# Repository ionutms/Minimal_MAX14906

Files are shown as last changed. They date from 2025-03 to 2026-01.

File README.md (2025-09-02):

# Minimal_MAX14906

## Overview

This repository contains a minimal KiCad design project for the Analog Devices MAX14906, a quad-channel industrial digital I/O device. The project includes schematic designs and PCB layout files.

## Disclaimer

> [!NOTE]
> This project is provided "as is" and without any warranty, express or implied. For more details, please see the [LICENSE](LICENSE) file.

## About the MAX14906

The MAX14906 from Analog Devices is a quad-channel industrial digital input/output device for industrial control and automation applications. It is compliant with IEC 61131-2 standards.

Key features include:

- **Configurable Channels:** Each of the four channels can be independently configured as:
  - High-Side Switch
  - Push-Pull Driver
  - Digital Input (Type 1, 2, or 3)
- **Wide Operating Range:** 10V to 40V supply voltage range.
- **Robustness and Protection:** Features on-chip diagnostics like open-wire detection, thermal shutdown and undervoltage monitoring. It also features SafeDemag™ for safely turning off inductive loads.
- **Control Interface:** SPI interface for configuration and diagnostics.
- **Operating Temperature Range:** -40°C to +125°C.

## Project Structure

```
minimal_max14906/
├── minimal_max14906.kicad_sch       # Main schematic file
├── minimal_max14906.kicad_pcb       # PCB layout file
├── minimal_max14906.kicad_pro       # Project configuration file
├── fp-lib-table                     # Footprint library table
├── sym-lib-table                    # Symbol library table
├── project_jobs_set.kicad_jobset    # Project job settings
├── ibom.config.ini                  # Interactive BOM configuration
├── docs/                            # Documentation files
│   ├── pictures/                    # Images and photos
│   ├── schematics/                  # Schematic PDF exports
│   └── 3d_models/                   # 3D model files
└── KiCAD_Symbols_Generator/         # Submodule for symbol generation from CSV data
```

## Project Features

This design provides a minimal implementation of the MAX14906 with the following features:

- **Power Supply:**
  - VDD: +24V
  - VSS: 0V
  - VLOGIC: +3.3V
- **Channel Configuration:**
  - Basic protection circuits for each of the four I/O channels.
- **Bill of Materials (BOM):**
  - Interactive HTML BOM (`ibom.html`) for easy component identification and sourcing.
- **Libraries:**
  - Comprehensive symbol and footprint libraries integrated as a submodule.
- **3D Model:**
  - Includes a 3D model of the board for better visualization.

## Getting Started

### Prerequisites

- [KiCad EDA](https://www.kicad.org/) version 9.0 or later installed on your system
- Git (for cloning the repository and submodule management)

### Opening the Project

1. **Clone the repository** (including submodules):
   ```bash
   git clone --recursive https://github.com/ionutms/Minimal_MAX14906.git
   ```
   
   If you've already cloned the repository without submodules, initialize them with:
   ```bash
   git submodule init
   git submodule update
   ```

2. **Open the project in KiCad**:
   - Launch KiCad
   - Click "Open Existing Project"
   - Navigate to the cloned repository folder
   - Select the `minimal_max14906.kicad_pro` file

3. **Explore the design**:
   - Open the schematic editor to view the circuit design
   - Open the PCB editor to view the board layout
   - Review the symbol and footprint libraries used in the design

### Project Files

- **Main schematic**: `minimal_max14906.kicad_sch` - Contains the primary circuit design with the MAX14906 and support components
- **PCB layout**: `minimal_max14906.kicad_pcb` - Physical board design file with proper component placement
- **Project configuration**: `minimal_max14906.kicad_pro` - KiCad project settings

## Dependencies

This project has the following dependencies:

### 1. KiCAD Symbols Generator

This repository uses [KiCAD_Symbols_Generator](https://github.com/ionutms/KiCAD_Symbols_Generator) as a submodule for custom symbol generation.

To initialize the submodule after cloning this repository:

```bash
git submodule update --init --recursive
```

### 2. 3D Models

This project requires the [3D_Models_Vault](https://github.com/ionutms/3D_Models_Vault) repository for 3D models.

#### Setup for KiCAD 9:

1. Clone the 3D models repository:
   ```bash
   git clone https://github.com/ionutms/3D_Models_Vault.git
   ```

2. In KiCAD 9, add an environment variable:
   - Variable name: `KICAD9_3D_MODELS_VAULT`
   - Variable value: Full path to where you cloned the 3D_Models_Vault repository

## Usage

After setting up the dependencies, open the project in KiCad 9 to access all features including the 3D models.

## Symbol Generator Submodule

This project includes the KiCAD_Symbols_Generator as a submodule, which provides tools for generating KiCad symbols from CSV data files. For more information on using this tool, see the [KiCAD_Symbols_Generator documentation](minimal_max14906/KiCAD_Symbols_Generator/README.md).

## Documentation

The `docs` folder contains:
- Schematic PDF exports
- Images and photos of the design
- 3D model files (GLB and WRL formats)

## Visuals

The following images showcase the PCB design from different perspectives:

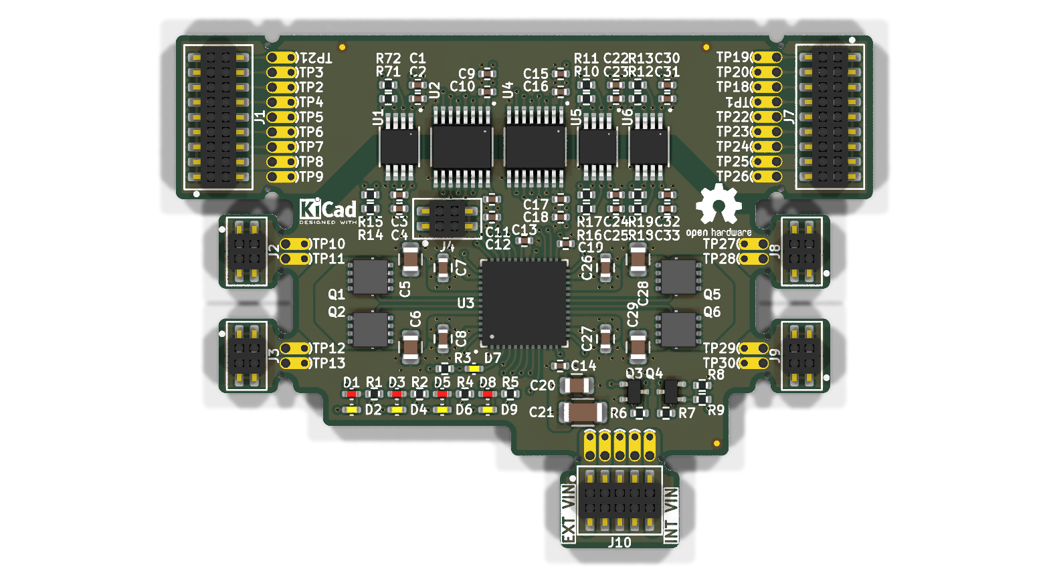
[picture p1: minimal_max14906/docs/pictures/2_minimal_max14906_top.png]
Top View

*Top View of the PCB*

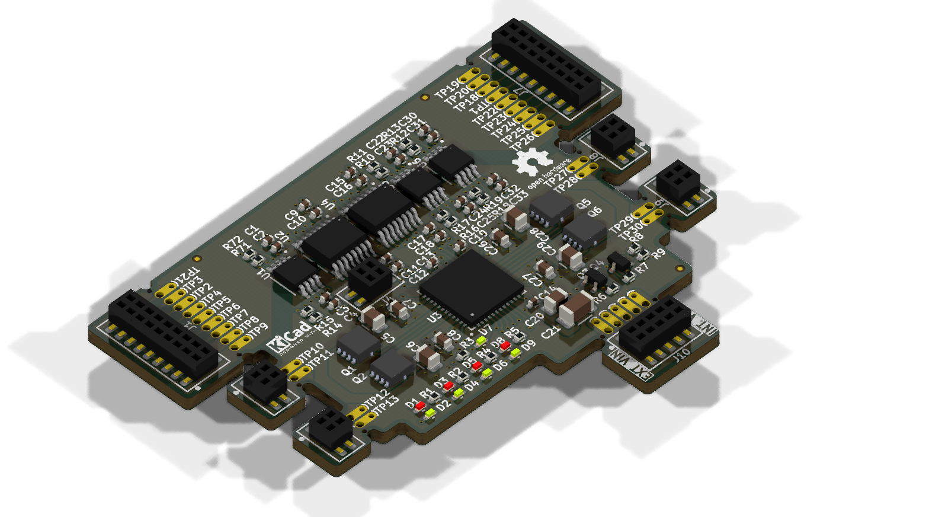
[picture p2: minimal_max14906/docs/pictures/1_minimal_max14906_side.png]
Side View

*Side View of the PCB*

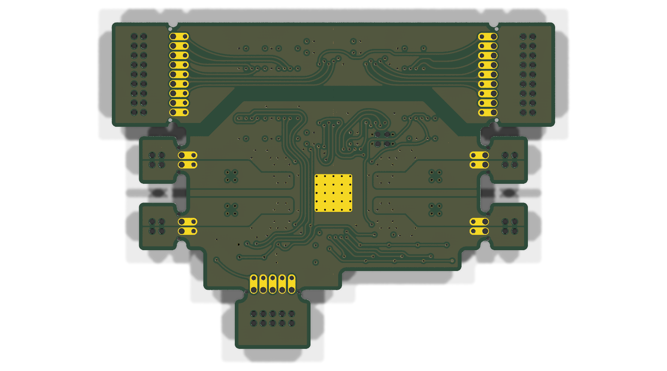
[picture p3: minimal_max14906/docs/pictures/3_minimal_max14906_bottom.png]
Bottom View

*Bottom View of the PCB*

## License

This project is licensed under the MIT License - see the [LICENSE](LICENSE) file for details.

## References

- [MAX14906 Datasheet](https://www.analog.com/en/products/max14906.html)
- [KiCad EDA](https://www.kicad.org/)

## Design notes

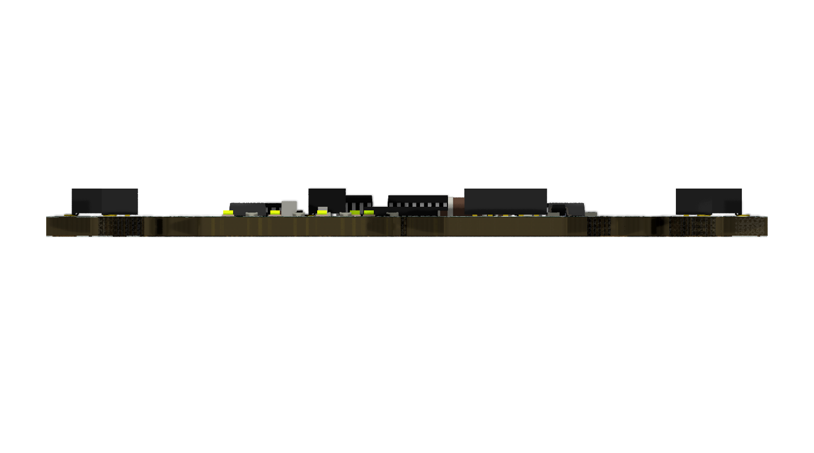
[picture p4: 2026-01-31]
minimal_max14906/docs/pictures/6_minimal_max14906_front.png

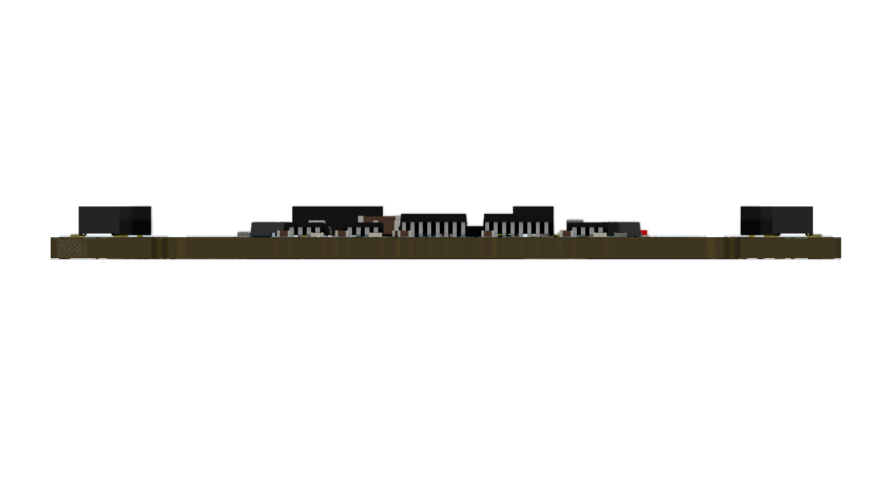
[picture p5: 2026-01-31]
minimal_max14906/docs/pictures/7_minimal_max14906_back.png

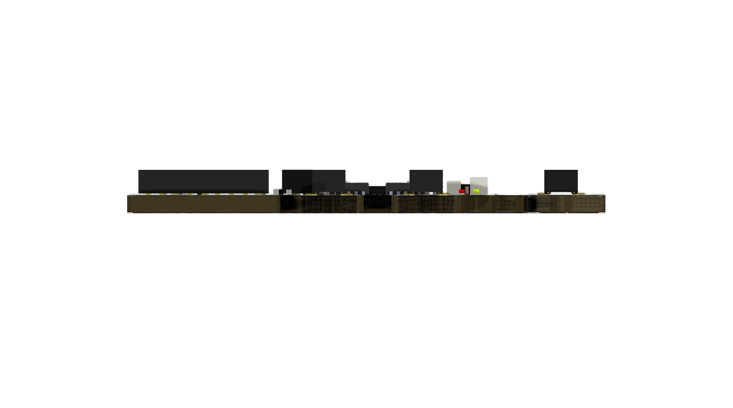
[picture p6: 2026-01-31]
minimal_max14906/docs/pictures/4_minimal_max14906_left.png

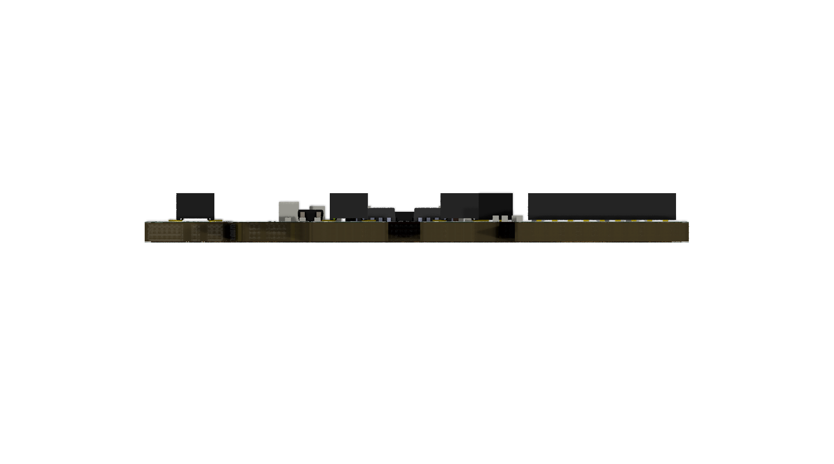
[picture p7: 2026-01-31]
minimal_max14906/docs/pictures/5_minimal_max14906_right.png

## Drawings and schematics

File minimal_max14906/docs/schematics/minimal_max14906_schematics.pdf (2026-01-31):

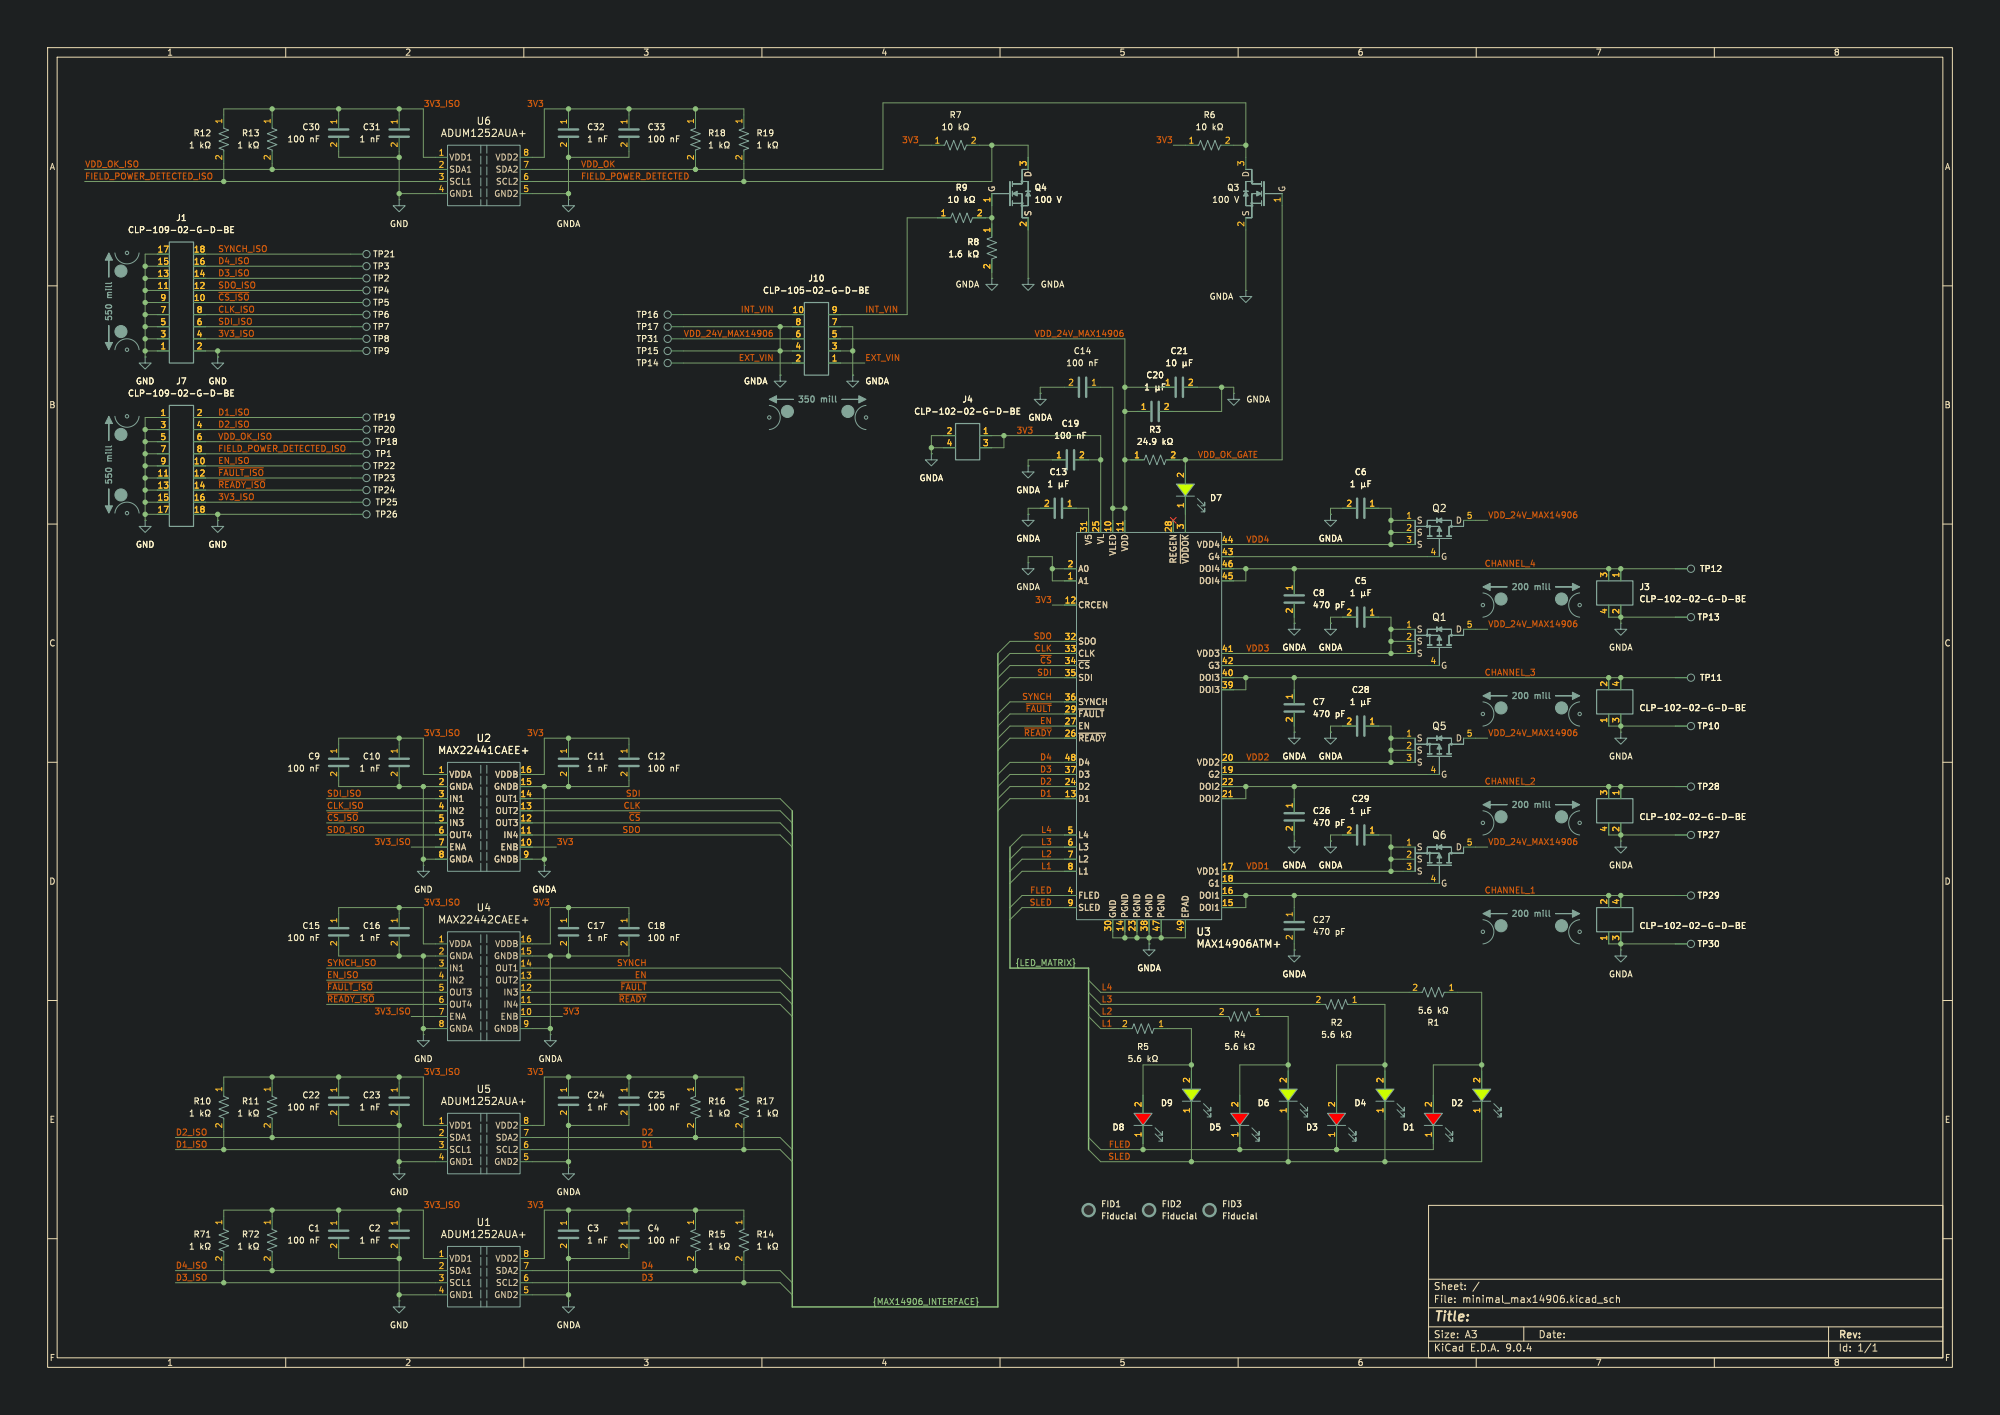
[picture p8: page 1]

~{READY} SDI ~{CS} SDO

Id: 1/1 Title: File: minimal_max14906.kicad_sch Sheet: /

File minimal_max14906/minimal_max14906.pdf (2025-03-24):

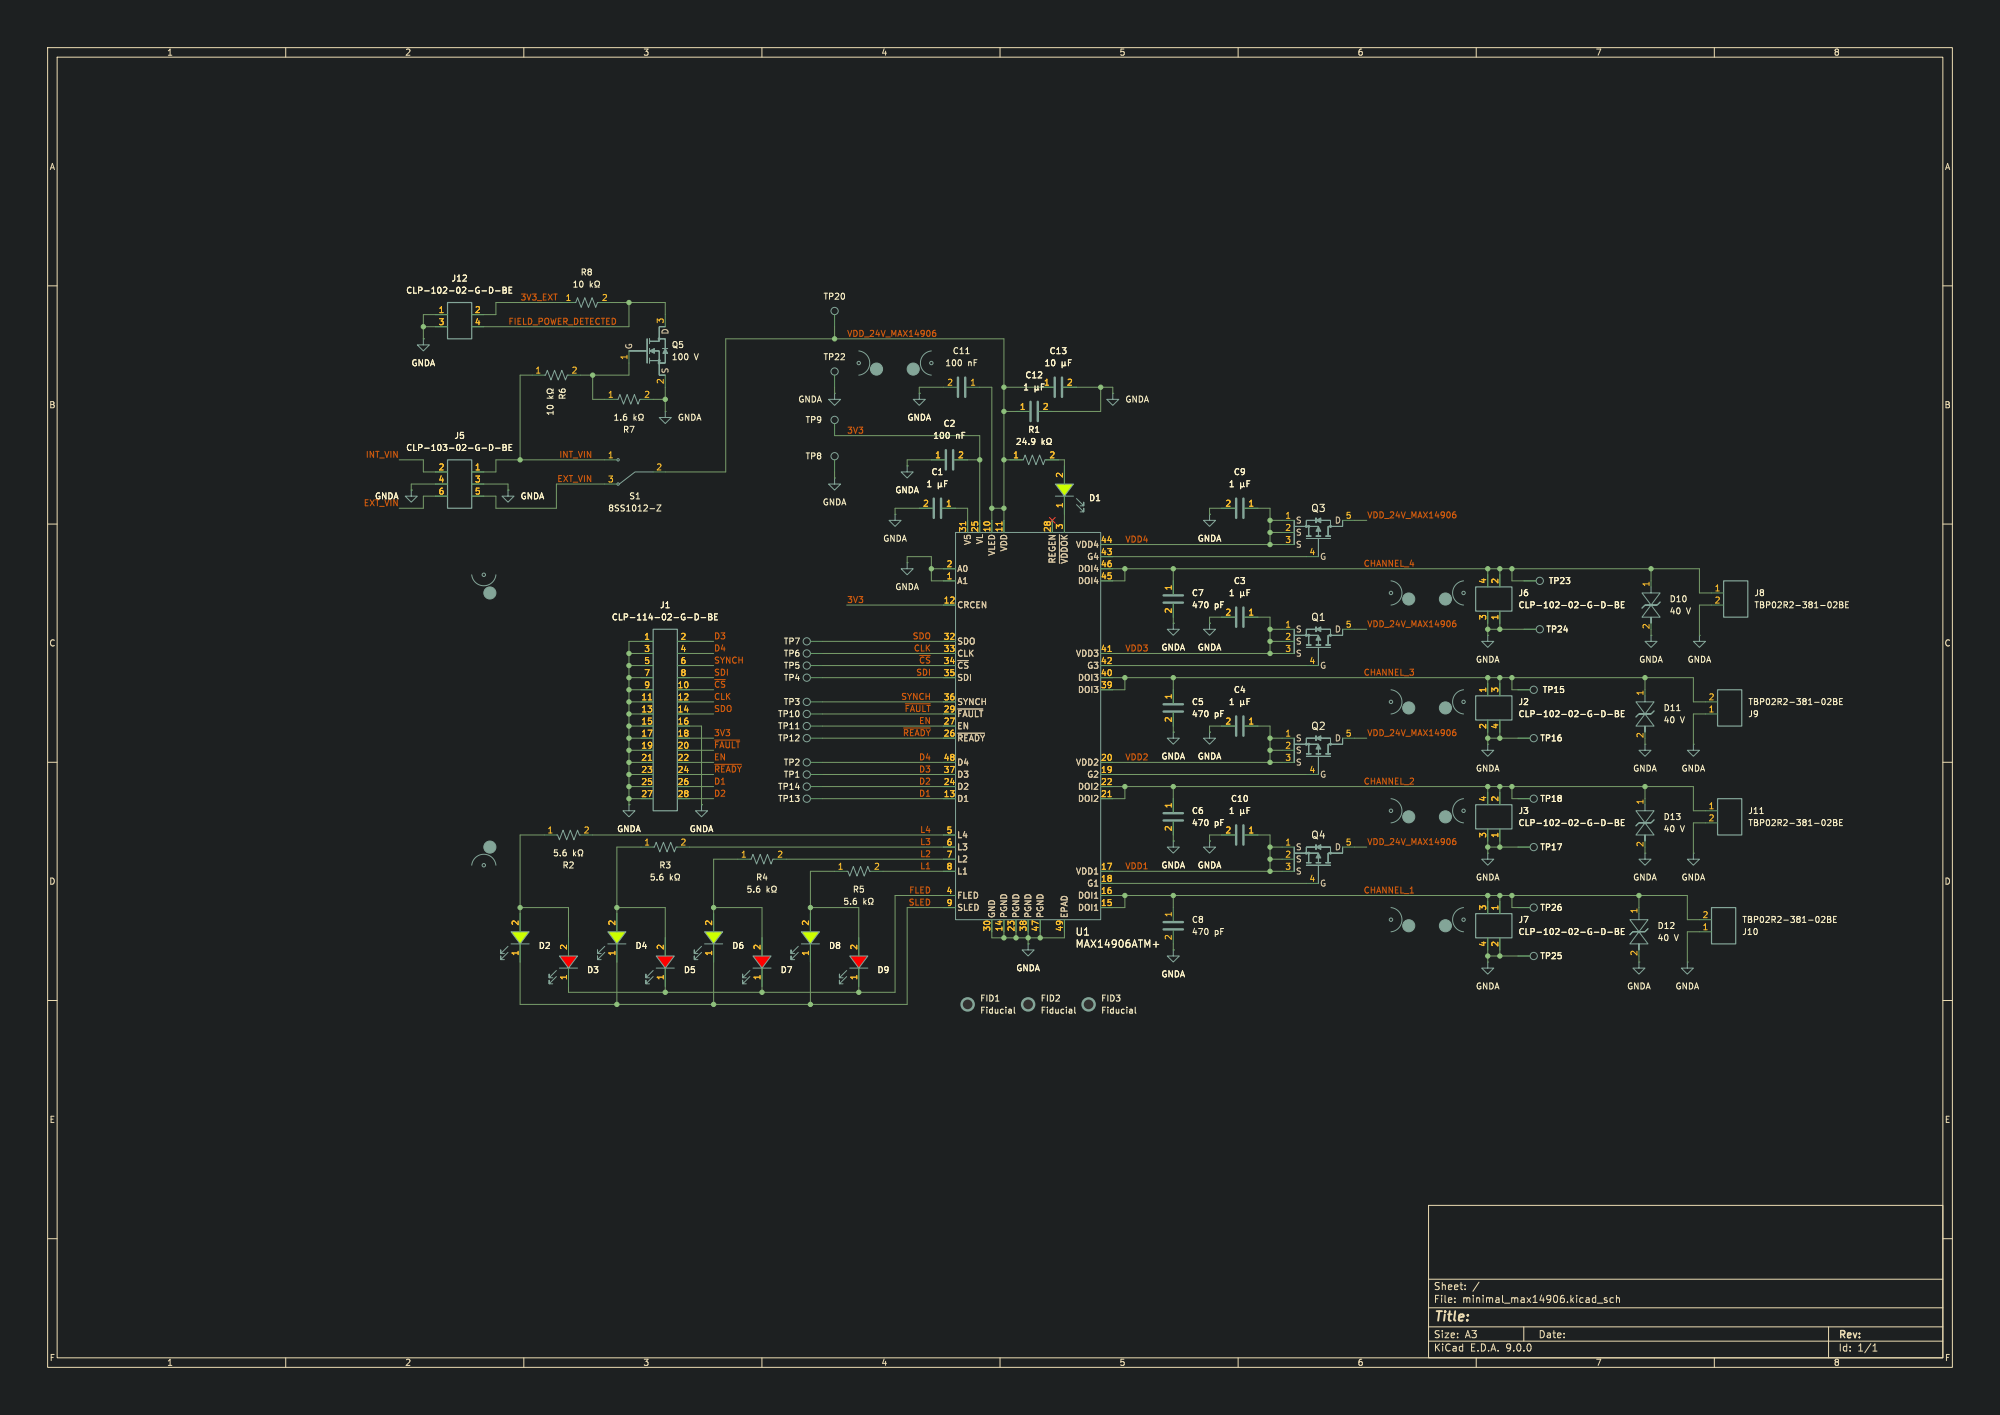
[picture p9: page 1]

Id: 1/1 Title: File: minimal_max14906.kicad_sch Sheet: / FID1 Fiducial TP10

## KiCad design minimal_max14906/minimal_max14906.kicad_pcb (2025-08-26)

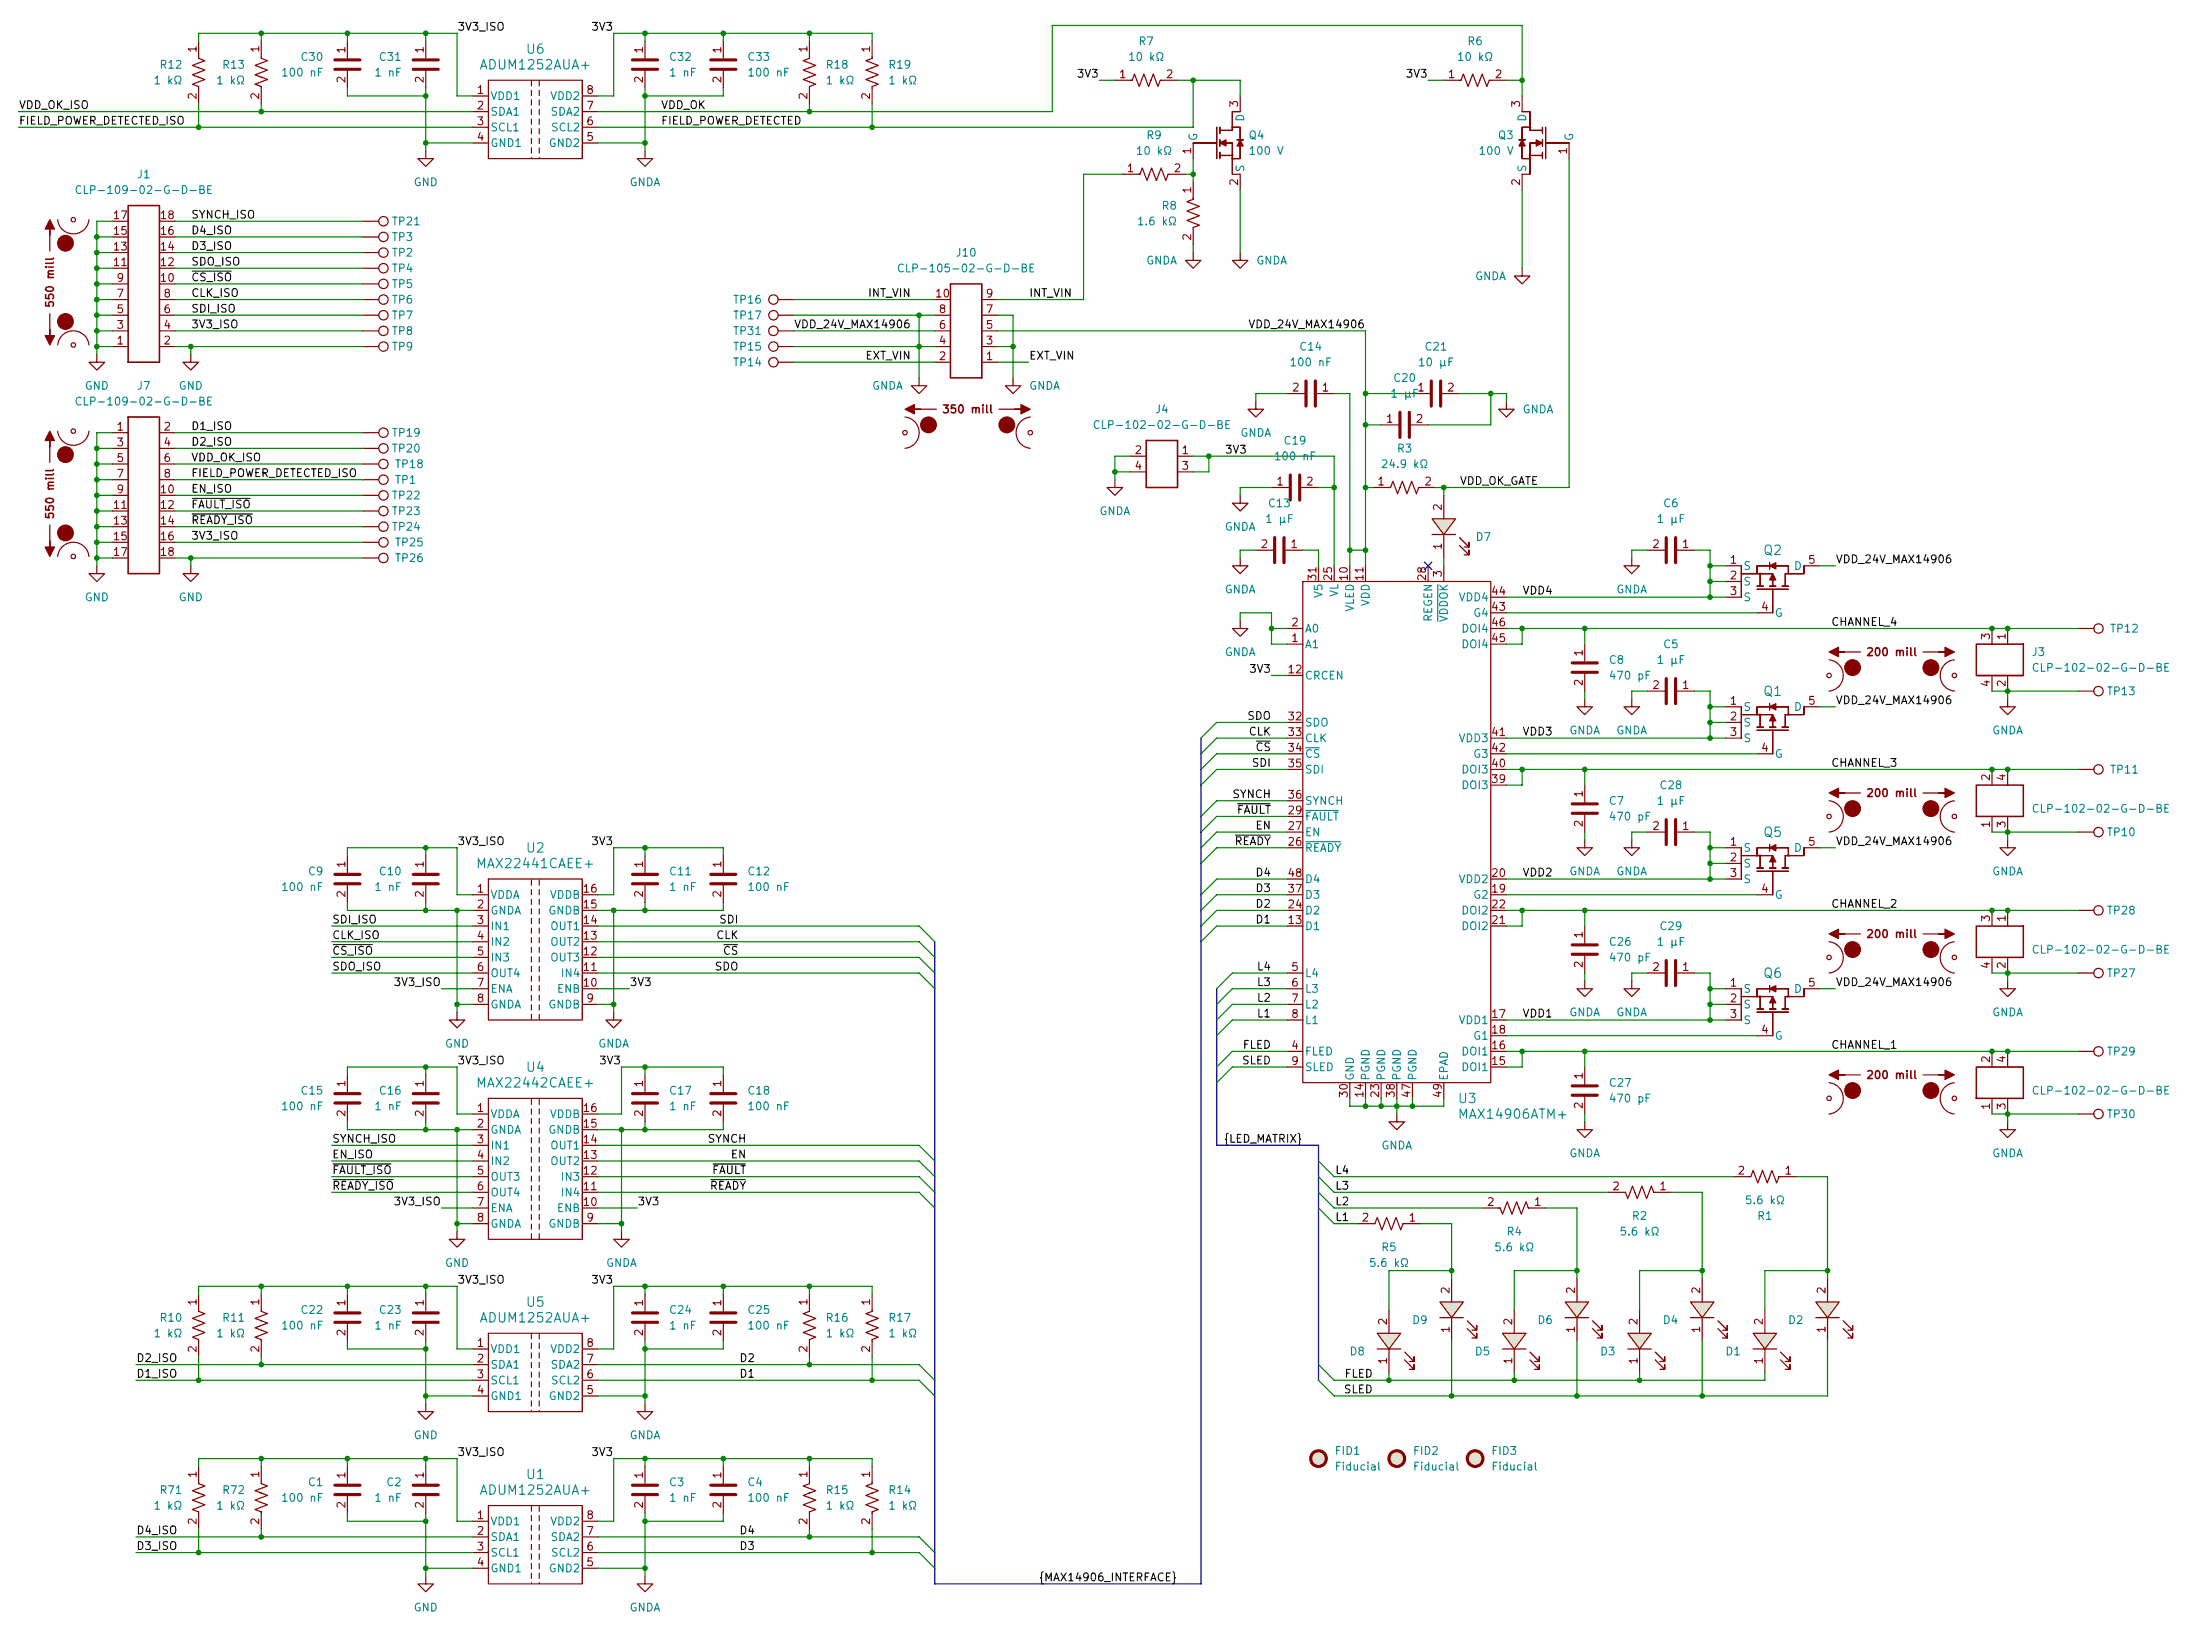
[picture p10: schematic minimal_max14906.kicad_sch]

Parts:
C1, C4, C9, C12, C14, C15, C18, C19, C22, C25, C30, C33: 100 nF; C_0402_1005Metric; Voltage Rating DC 50 VDC; Tolerance 10%; MPN GCM155R71H104KE02D
C2, C3, C10, C11, C16, C17, C23, C24, C31, C32: 1 nF; C_0402_1005Metric; Tolerance 10%; Voltage Rating 50V; MPN GCM155R71H102KA37D
C5, C6, C20, C28, C29: 1 µF; C_0805_2012Metric; Voltage Rating DC 100 VDC; Tolerance 10%; MPN GRJ21BC72A105KE11L
C7, C8, C26, C27: 470 pF; C_0603_1608Metric; Voltage Rating DC 100 VDC; Tolerance 10%; MPN VJ0603Y471KXBAC
C13: 1 µF; C_0402_1005Metric; Voltage Rating DC 16 VDC; Tolerance 10%; MPN C1005X6S1C105K050BC
C21: 10 µF; C_1206_3216Metric; Voltage Rating DC 50 VDC; Tolerance 10%; MPN CL31B106KBHNNN#
D1, D3, D5, D8: 1.8 V; LED_RED_0402_1005Metric; MPN APHHS1005LSECK/J3-PF
D2, D4, D6, D7, D9: 1.8 V; LED_GREEN_0402_1005Metric; MPN APHHS1005CGCK
FID1, FID2, FID3: Fiducial; Fiducial_0.5mm_Mask1mm
J1, J7: CLP-109-02-G-D-BE; Current Rating (A) 5.2; Voltage Rating (V) 300; MPN CLP-109-02-G-D-BE
J2, J3, J4, J8, J9: CLP-102-02-G-D-BE; Current Rating (A) 5.2; Voltage Rating (V) 300; MPN CLP-102-02-G-D-BE
J10: CLP-105-02-G-D-BE; Current Rating (A) 5.2; Voltage Rating (V) 300; MPN CLP-105-02-G-D-BE
MB1, MB6: mouse-bite-50mil-550mil
MB2, MB3, MB7, MB8: mouse-bite-50mil-200mil
MB4: mouse-bite-50mil-300mil; mouse-bite-50mil-350mil
Q1, Q2, Q5, Q6: -60.0 V; PowerPAK 1212-8; MPN SI7309DN-T1-GE3
Q3, Q4: 100 V; SOT-323; MPN BSS123WQ-7-F
R1, R2, R4, R5: 5.6 kΩ; R_0402_1005Metric; Voltage Rating 50V; Tolerance 5%; MPN RMCF0402JT5K60
R3: 24.9 kΩ; R_0402_1005Metric; Voltage Rating 50V; Tolerance 1%; MPN ERJ-2RKF2492X
R6, R7, R9: 10 kΩ; R_0402_1005Metric; Tolerance 1%; Voltage Rating 50V; MPN ERJ-2RKF1002X
R8: 1.6 kΩ; R_0402_1005Metric; Tolerance 1%; Voltage Rating 50V; MPN ERJ-2RKF1601X
R10, R11, R12, R13, R14, R15, R16, R17, R18, R19, R71, R72: 1 kΩ; R_0402_1005Metric; Tolerance 1%; Voltage Rating 50V; MPN ERJ-2RKF1001X
TP1, TP2, TP3, TP4, TP5, TP6, TP7, TP8, TP9, TP10, TP11, TP12, TP13, TP14, TP15, TP16, TP17, TP18, TP19, TP20, TP21, TP22, TP23, TP24, TP25, TP26, TP27, TP28, TP29, TP30, TP31: TestPoint; TestPoint_THTPad_Castelated
U1, U5, U6: ADUM1252AUA+; 21-0036_ADI; MPN ADUM1252AUA+
U2: MAX22441CAEE+; 21-0055_E16MS&plus_1F_ADI; MPN MAX22441CAEE+
U3: MAX14906ATM+; 21-0144H_T4877-6; MPN MAX14906ATM+
U4: MAX22442CAEE+; 21-0055_E16MS&plus_1F_ADI; MPN MAX22442CAEE+

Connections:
/3V3: C3.1, C4.1, C11.1, C12.1, C17.1, C18.1, C19.2, C24.1, C25.1, C32.1, C33.1, J4.1, J4.3, R6.1, R7.1, R14.1, R15.1, R16.1, R17.1, R18.1, R19.1, U1.8 (VDD2), U2.10 (ENB), U2.16 (VDDB), U3.12 (CRCEN), U3.25 (VL), U4.10 (ENB), U4.16 (VDDB), U5.8 (VDD2), U6.8 (VDD2)
/3V3_ISO: C1.1, C2.1, C9.1, C10.1, C15.1, C16.1, C22.1, C23.1, C30.1, C31.1, J1.4, J7.16, R10.1, R11.1, R12.1, R13.1, R71.1, R72.1, TP8.1, TP25.1, U1.1 (VDD1), U2.1 (VDDA), U2.7 (ENA), U4.1 (VDDA), U4.7 (ENA), U5.1 (VDD1), U6.1 (VDD1)
/CHANNEL_1: C27.1, J9.2, J9.4, TP29.1, U3.15 (DOI1), U3.16 (DOI1)
/CHANNEL_2: C26.1, J8.1, J8.3, TP28.1, U3.21 (DOI2), U3.22 (DOI2)
/CHANNEL_3: C7.1, J2.2, J2.4, TP11.1, U3.39 (DOI3), U3.40 (DOI3)
/CHANNEL_4: C8.1, J3.1, J3.3, TP12.1, U3.45 (DOI4), U3.46 (DOI4)
/CLK: U2.13 (OUT2), U3.33 (CLK)
/CLK_ISO: J1.8, TP6.1, U2.4 (IN2)
/D1: R17.2, U3.13 (D1), U5.6 (SCL2)
/D1_ISO: J7.2, R10.2, TP19.1, U5.3 (SCL1)
/D2: R16.2, U3.24 (D2), U5.7 (SDA2)
/D2_ISO: J7.4, R11.2, TP20.1, U5.2 (SDA1)
/D3: R14.2, U1.6 (SCL2), U3.37 (D3)
/D3_ISO: J1.14, R71.2, TP2.1, U1.3 (SCL1)
/D4: R15.2, U1.7 (SDA2), U3.48 (D4)
/D4_ISO: J1.16, R72.2, TP3.1, U1.2 (SDA1)
/EN: U3.27 (EN), U4.13 (OUT2)
/EN_ISO: J7.10, TP22.1, U4.4 (IN2)
/EXT_VIN: J10.1, J10.2, TP14.1
/FIELD_POWER_DETECTED: Q4.3 (D), R7.2, R19.2, U6.6 (SCL2)
/FIELD_POWER_DETECTED_ISO: J7.8, R12.2, TP1.1, U6.3 (SCL1)
/FLED: D1.1, D3.1, D5.1, D8.1, U3.4 (FLED)
/INT_VIN: J10.9, J10.10, R9.1, TP16.1
/L1: R5.2, U3.8 (L1)
/L2: R4.2, U3.7 (L2)
/L3: R2.2, U3.6 (L3)
/L4: R1.2, U3.5 (L4)
/SDI: U2.14 (OUT1), U3.35 (SDI)
/SDI_ISO: J1.6, TP7.1, U2.3 (IN1)
/SDO: U2.11 (IN4), U3.32 (SDO)
/SDO_ISO: J1.12, TP4.1, U2.6 (OUT4)
/SLED: D2.1, D4.1, D6.1, D9.1, U3.9 (SLED)
/SYNCH: U3.36 (SYNCH), U4.14 (OUT1)
/SYNCH_ISO: J1.18, TP21.1, U4.3 (IN1)
/VDD1: C29.1, Q6.1 (S), Q6.2 (S), Q6.3 (S), U3.17 (VDD1)
/VDD2: C28.1, Q5.1 (S), Q5.2 (S), Q5.3 (S), U3.20 (VDD2)
/VDD3: C5.1, Q1.1 (S), Q1.2 (S), Q1.3 (S), U3.41 (VDD3)
/VDD4: C6.1, Q2.1 (S), Q2.2 (S), Q2.3 (S), U3.44 (VDD4)
/VDD_24V_MAX14906: C14.1, C20.1, C21.1, J10.5, J10.6, Q1.5 (D), Q2.5 (D), Q5.5 (D), Q6.5 (D), R3.1, TP31.1, U3.10 (VLED), U3.11 (VDD)
/VDD_OK: Q3.3 (D), R6.2, R18.2, U6.7 (SDA2)
/VDD_OK_GATE: D7.2, Q3.1 (G), R3.2
/VDD_OK_ISO: J7.6, R13.2, TP18.1, U6.2 (SDA1)
/~CS_ISO: J1.10, TP5.1, U2.5 (IN3)
/~CS: U2.12 (OUT3), U3.34 (~CS)
/~FAULT_ISO: J7.12, TP23.1, U4.5 (OUT3)
/~FAULT: U3.29 (~FAULT), U4.12 (IN3)
/~READY_ISO: J7.14, TP24.1, U4.6 (OUT4)
/~READY: U3.26 (~READY), U4.11 (IN4)
GND: C1.2, C2.2, C9.2, C10.2, C15.2, C16.2, C22.2, C23.2, C30.2, C31.2, J1.1, J1.2, J1.3, J1.5, J1.7, J1.9, J1.11, J1.13, J1.15, J1.17, J7.1, J7.3, J7.5, J7.7, J7.9, J7.11, J7.13, J7.15, J7.17, J7.18, TP9.1, TP26.1, U1.4 (GND1), U2.2 (GNDA), U2.8 (GNDA), U4.2 (GNDA), U4.8 (GNDA), U5.4 (GND1), U6.4 (GND1)
GNDA: C3.2, C4.2, C5.2, C6.2, C7.2, C8.2, C11.2, C12.2, C13.2, C14.2, C17.2, C18.2, C19.1, C20.2, C21.2, C24.2, C25.2, C26.2, C27.2, C28.2, C29.2, C32.2, C33.2, J2.1, J2.3, J3.2, J3.4, J4.2, J4.4, J8.2, J8.4, J9.1, J9.3, J10.3, J10.4, J10.7, J10.8, Q3.2 (S), Q4.2 (S), R8.2, TP10.1, TP13.1, TP15.1, TP17.1, TP27.1, TP30.1, U1.5 (GND2), U2.9 (GNDB), U2.15 (GNDB), U3.1 (A1), U3.2 (A0), U3.14 (PGND), U3.23 (PGND), U3.30 (GND), U3.38 (PGND), U3.47 (PGND), U3.49 (EPAD), U4.9 (GNDB), U4.15 (GNDB), U5.5 (GND2), U6.5 (GND2)
unnamed: D1.2, D2.2, R1.1
unnamed: D3.2, D4.2, R2.1
unnamed: D5.2, D6.2, R4.1
unnamed: D8.2, D9.2, R5.1
unnamed: Q1.4 (G), U3.42 (G3)
unnamed: Q2.4 (G), U3.43 (G4)
unnamed: Q4.1 (G), R8.1, R9.2
unnamed: Q5.4 (G), U3.19 (G2)
unnamed: Q6.4 (G), U3.18 (G1)
unnamed: C13.1, U3.31 (V5)
unnamed: D7.1, U3.3 (~VDDOK)

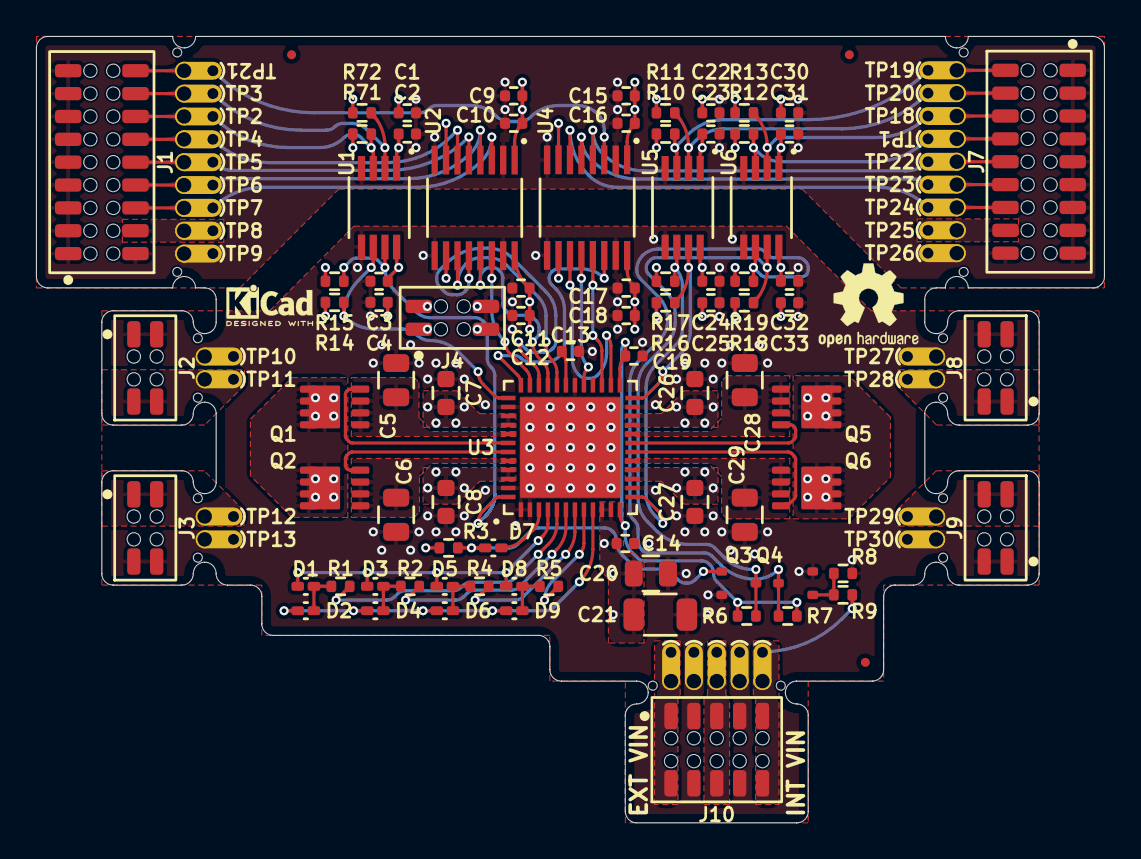
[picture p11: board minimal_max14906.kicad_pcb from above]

Board: 4 copper layers, 59.3 x 43.7 mm, 124 parts (0 on the bottom side), 61 nets.

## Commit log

2025-01-18 Update clone and visitor statistics for 2025-01-18 13:25:10 EET
    [clones_history.csv, visitors_history.csv]
2025-01-18 Create the Kicad project
    [minimal_max14906.kicad_pcb, minimal_max14906.kicad_sch]
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2025-01-21 Add initial version
    [minimal_max14906.kicad_pcb, minimal_max14906.kicad_sch]
2025-01-21 minor changes
    [minimal_max14906.kicad_pcb]
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2025-01-22 minor updates
    [minimal_max14906.kicad_sch]
2025-01-28 Update subproject commit for KiCAD Symbol Generator
    [minimal_max14906.kicad_pcb, minimal_max14906.kicad_sch]
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2025-01-30 Minor updates to project files
    [minimal_max14906.kicad_pcb]
2025-01-31 Update KiCAD Symbol Generator subproject commit and adjust pad dimensions
    [minimal_max14906.kicad_pcb]
2025-02-03 Minor updates to improve project consistency
    [minimal_max14906.kicad_pcb]
2025-02-05 Minor updates for project consistency
    [minimal_max14906.kicad_pcb]
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2025-02-07 Update KiCAD Symbol Generator and configuration files
    [minimal_max14906.kicad_pcb, minimal_max14906.kicad_sch]
2025-03-01 Update KiCAD Symbol Generator subproject and add new footprints for fiducial markers
    [minimal_max14906.kicad_pcb, minimal_max14906.kicad_sch]
2025-03-02 Update KiCAD Symbol Generator with new features and improvements
    [minimal_max14906.kicad_pcb, minimal_max14906.kicad_sch]
2025-03-02 Update KiCAD Symbol Generator with enhancements and bug fixes
    [minimal_max14906.kicad_pcb]
2025-03-02 Update KiCAD schematic references for consistency and accuracy
    [minimal_max14906.kicad_pcb, minimal_max14906.kicad_sch]
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2025-03-10 Update KiCAD schematic references for improved clarity and consistency
    [minimal_max14906.kicad_pcb]
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2025-03-16 Update KiCAD Symbols Generator submodule and adjust library paths in fp-lib-table
    [minimal_max14906.kicad_pcb]
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2025-03-18 Switch to KiCad 9
    [minimal_max14906.kicad_pcb, minimal_max14906.kicad_sch]
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2025-03-20 Add new special_execute command for rendering top PCB image in project job set configuration
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2025-03-20 Add top image and update file references for minimal_max14906
    [minimal_max14906.kicad_pcb]
2025-03-22 Update README.md to include project dependencies and setup instructions for KiCAD and 3D models
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2025-03-24 Update pad dimensions and add net colors for minimal_max14906
    [minimal_max14906.kicad_pcb, minimal_max14906.kicad_sch]
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2025-04-04 development backup
    [minimal_max14906.kicad_pcb, minimal_max14906.kicad_sch]
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2025-04-05 Update schematic PDF for minimal_max14906 with formatting adjustments and corrections
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2025-04-19 dev backup
    [minimal_max14906.kicad_pcb]
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2025-04-20 Refactor KiCad job to generate schematic PDF and PCB render on the same step
2025-04-20 Update KiCad configuration and workflow to use project zoom factor for top view rendering
2025-04-20 Fix formatting in KiCad job for PCB render command
2025-04-20 Fix quotes in PCB render command options for consistency
2025-04-20 Refactor KiCad job to streamline PCB rendering steps and improve directory management
2025-04-20 Fix formatting in PCB render command options for consistency
2025-04-20 Add rotation coordinates to KiCad configuration and update workflow to use them
2025-04-20 Fix quotes in KiCad configuration for project rotation coordinates
2025-04-20 Fix quotes in PCB render command options for rotate parameter
2025-04-20 Fix rotation parameter in PCB render command for consistency
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2025-04-20 Fix escape character in rotation coordinates in KiCad configuration
2025-04-20 Fix rotation coordinates formatting in KiCad configuration and workflow
2025-04-20 Fix rotation coordinates syntax in KiCad output generation
2025-04-20 Fix rotation coordinates extraction and export in KiCad workflow
2025-04-20 Fix handling of custom rotation coordinates in KiCad workflow
2025-04-20 Fix formatting of default rotation coordinates in KiCad workflow
2025-04-20 Refactor KiCad workflow to standardize zoom factor extraction and remove unused rotation coordinates
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2025-04-20 Update PCB render generation to use fixed rotation angles
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2025-04-20 Fix rotation factor variable usage in PCB render generation
2025-04-20 Refactor zoom factor extraction and update PCB rendering to use custom zoom value from configuration
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2025-04-20 Rename PCB rendering step and update zoom factor for improved output quality
2025-04-20 Fix formatting in PCB rendering command for consistent rotation parameters
2025-04-20 Fix quoting in PCB rendering command for proper argument handling
2025-04-20 Fix PCB rendering command to handle errors gracefully and improve rotation parameter formatting
2025-04-20 Fix PCB rendering command to use zoom factor from configuration and update output file naming
2025-04-20 Refactor PCB rendering step to use jobset command and remove commented-out code
2025-04-20 Enhance PCB rendering step to restore functionality and utilize zoom factor from configuration
2025-04-20 Fix PCB rendering command to correctly apply zoom factor and adjust rotation parameters
2025-04-20 Update PCB rendering command to use variables for rotation and pan parameters
2025-04-20 Refactor PCB rendering command to use double quotes for rotation parameters and remove unused pan variable
2025-04-20 Fix PCB rendering command to remove unnecessary quotes around rotation parameter
2025-04-20 Comment out PDF schematic generation step and adjust PCB rendering command for rotation parameter
2025-04-20 Fix PCB rendering command to properly format rotation parameter
2025-04-20 Refactor PDF schematic generation and PCB rendering commands for improved clarity and maintainability
2025-04-20 Refactor PCB rendering command to streamline Docker execution and improve script clarity
2025-04-20 Fix rotation parameter syntax in PCB rendering command
2025-04-20 Refactor PCB 3D rendering command to streamline environment setup and remove unnecessary test step
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2025-04-20 Remove merge conflict markers and clean up PCB rendering command in KiCad job workflow
2025-04-20 Refactor zoom factor handling in KiCad job configuration to ensure default values are used when configuration file is absent
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2025-04-21 Fix zoom factor extraction and improve PCB rendering command output
2025-04-21 Update default zoom factor and adjust PCB rendering command parameters for improved output
2025-04-21 Fix default zoom factor assignment in KiCad job configuration
2025-04-21 Fix output path for KiCad 3D models in rendering step
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2025-04-21 Update zoom factor handling in KiCad job workflow to use side view zoom factor from configuration
2025-04-21 Refactor zoom factor extraction in KiCad job workflow to improve variable naming
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2025-04-21 Enhance KiCad job workflow to extract and utilize side view parameters from configuration
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2025-04-21 Enhance PCB rendering in KiCad job workflow with top and side view generation
2025-04-21 Update KiCad configuration and job workflow to include top view zoom factor
2025-04-21 Fix indentation in KiCad configuration for side view pan setting
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2025-04-21 Update KiCad documentation workflow to create project-specific directories and adjust file paths
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2025-04-21 Fix output filename for KiCad schematic PDF generation
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2025-04-21 Fix casing for 3D model directories in KiCad documentation generation
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2025-05-23 Enhance 3D model export by including tracks, pads, zones, silkscreen, and soldermask
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
